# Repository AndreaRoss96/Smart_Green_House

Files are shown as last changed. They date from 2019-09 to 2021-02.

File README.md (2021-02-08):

# Smart_Green_House
integrated embedded system that represents a simplified version of a smart greenhouse.

The task of the smart greenhouse is the automated irrigation (of a certain soil or plant) by implementing a strategy that takes into account the perceived humidity, with the possibility to control and intervene manually via mobile app.

The system is composed by 5 subsystems:
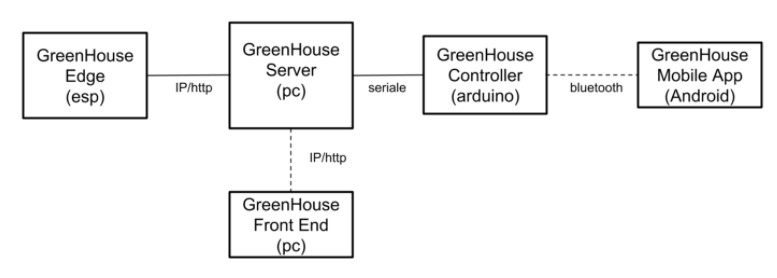
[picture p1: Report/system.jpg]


 * GreenHouse Server (PC)
    - contains the logic that defines and implements the irrigation strategy
 * GreenHouse Controller (Arduino)
   - allows you to control the opening and closing of the sprinklers (water pumps), thus the amount of water delivered per minute
 * GreenHouse Edge (ESP)
   - allows you to sense the humidity of the soil
 * GreenHouse Mobile App (Android) 
   - allows manual control of the greenhouse 
 * GreenHouse Front End (PC)
   - Front end for data visualisation/observation/analysis

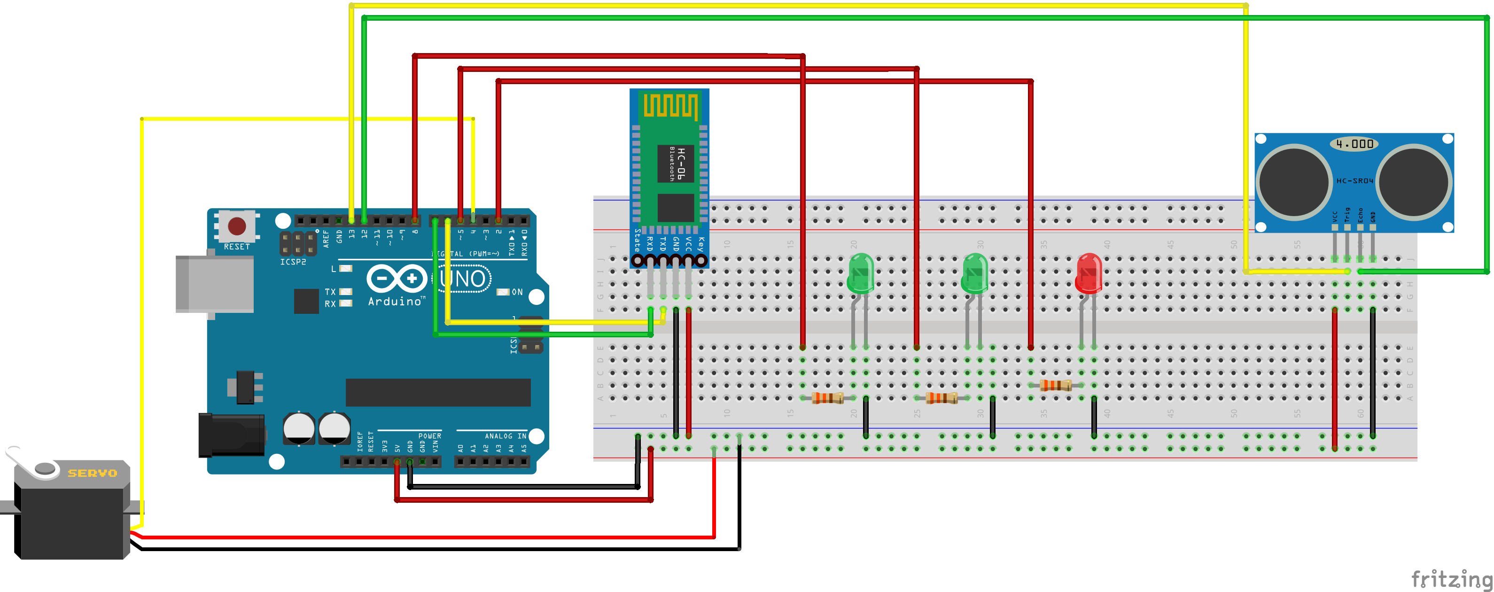
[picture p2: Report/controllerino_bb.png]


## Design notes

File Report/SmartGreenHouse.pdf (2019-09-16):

## Ingegneria e scienze informatiche (Cesena)

A.A 2018/19

## Valentini Luca Rossolini Andrea Orazi Filippo

obiettivi | 2
Analisi | 3
GreenHouse Controller | 3
Mobile App | 3
Progettazione | 4
Mobile App | 4
Microcontrollore | 4
Protocollo di comunicazione | 5
Edge ESP8266 | 6
Java Server (PC) | 6

# SmartGreenHouse

# obiettivi

Realizzare un sistema embedded che rappresenti una versione semplificata di una serra smart.
Il compito della serra smart è l’irrigazione automatizzata (di un certo terreno o pianta) implementando una strategia che tenga conto dell’umidità percepita, con la possibilità di controllare e intervenire manualmente mediante mobile app.

# Analisi

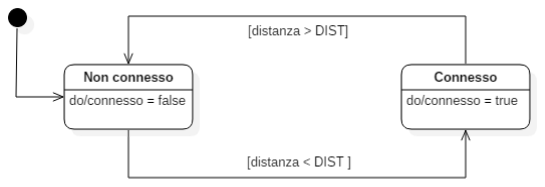
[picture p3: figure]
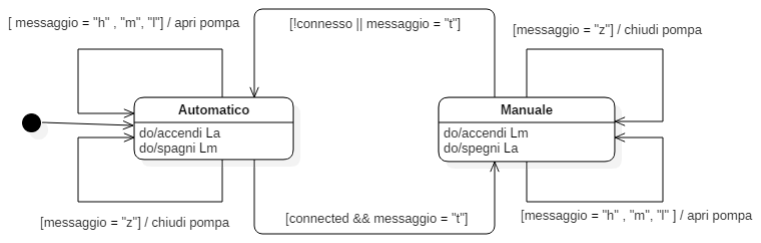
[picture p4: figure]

## GreenHouse Controller

Permette di controllare l’apertura e chiusura degli irrigatori (pompe acqua), quindi della quantità di acqua erogata al minuto. Riceve messaggi da bluetooth (se il dispositivo è nelle vicinanze) e da serial e li interpreta in modo da gestire la pompa.

## GreenHouse Edge

Percepisce l’umidità del terreno e la invia al server tramite Wifi.

## GreenHouse Server

Event driven loop che gestisce la comunicazione tra edge controller e front end, definisce e attua la strategia di irrigazione.

## GreenHouse Front End

Permette di osservare e analizzare dati

## Mobile App

L’app Android permetterà il controllo manuale della serra in maniera remota tramite bluetooth.
Considerando di essere nelle vicinanze della serra a una distanza dal Controller inferiore o uguale a 30 cm, deve essere possibile connettersi al sistema e passare a una modalità MANUALE in cui mediante l’app si possa:
- manualmente aprire/chiudere/regolare l’erogazione dell’acqua.
- visualizzare il valore corrente dell’umidità percepita.

# Progettazione

L’approccio da noi utilizzato nello sviluppo di questo software concorrente è la decomposizione del comportamento complessivo in più task:
– Ogni task rappresenta una fase ben definita, con un relativo compito da svolgere.
– Il comportamento di ogni task viene rappresentato da un elemento della macchina a stati, come rappresentato in figura.

## Mobile App

L’app è sviluppata in java in una singola activity chiamata MainActivity.
Questa schermata permetterà di svolgere tutte le funzioni richieste in fase di analisi, come:
- connessione ad arduino via bluetooth
- visualizzazione dello stato della connessione
- modalità automatica o manuale
- chiusura o apertura della pompa
- percentuale di umidità.

Per un corretto funzionamento dell’app è importante che prima di utilizzarla si effettui la connessione bluetooth con arduino, in modo tale da poter avere un canale di comunicazione tra lo smartphone e il micro-controllore.
A connessione avvenuta l’utente potrà cliccare i radio button per l’apertura e chiusura della pompa.
La comunicazione con arduino è bidirezionale, ovvero entrambi invieranno e riceveranno dei dati.

Ad ogni click dei pulsanti l’app invierà ad arduino una stringa secondo il protocollo di comunicazione da noi creato. Un’altra importante funzionalità è quella di ricevere informazioni relative alla percentuale di umidità.

## Microcontrollore

Il microcontrollore arduino viene impiegato per mantenere la logica di funzionamento degli attuatori e sensori della serra ad esclusione del sensore di umidità. L'arduino ha il compito di verificare l'eventuale connessione di un utente attraverso il sensore di distanza, in caso di utente sufficientemente vicino questo viene considerato connesso tramite bluetooth. Lo stato di connessione e di non connessione rappresentano i primi due stati della macchina e le loro meccaniche sono incapsulate nella classe TaskSearch.

Compito del microcontrollore è anche quello di gestire e interpretare i messaggi che gli arrivano sia dal server tramite seriale sia dalla Mobile App tramite bluetooth. Per fare ciò è presente la classe TaskComunicate che, con riferimento allo stato della macchina presente nella classe globale, gestisce e valuta i messaggi inerenti allo stato del controllore azionando in maniera coerente la pompa di irrigazione con lo stato di controllo del sistema (Manuale o Automatico)

### Protocollo di comunicazione

| invio di messaggi verso bluetooth
xx-a | xx percentuale di umidità nell'aria - modalità automatica
xx-m | xx percentuale di umidità nell'aria - modalità manuale
| invio di messaggi verso server
o | pompa aperta (open)
c | pompa chiusa (close)
0 | modalità automatica
1 | modalità manuale

| ricezione di messaggi
l | portata bassa (low)
m | portata media (medium)
h | portata alta (high)
z | portata nulla (zero)
Hxx | umidità percentuale = xx (humidity)

## Edge ESP8266

Il modulo ESP ha il solo scopo di misurare gli indici di umidità del terreno, tramite un modulo DHT11 (Nel codice implementato, tutto ciò che concerne questo modulo è commentato, poiché al suo posto, per semplice comodità, viene utilizzato un potenziometro, in questo modo siamo in grado di regolare manualmente l’umidità per svolgere le dovute analisi), ed inviarle al server.

Infatti l’edge misura l’umidità ogni 10 secondi, incapsulando questa informazione in un file Json che, all’interno di un pacchetto HTTP, viene inviata al server.

L’invio del pacchetto avviene tramite il software “Ngrok”, questo programma fornisce un indirizzo verso il quale, il microcontrollore, può facilmente comunicare; il server e l’ESP dovranno però essere connessi alla stessa rete wifi. Ngrok si occuperà di fare ‘tunneling’, ascoltando i messaggi in arrivo all'indirizzo da lui messo a disposizione, verso una determinata porta del localhost.

## Java Server (PC)

Il server contiene la logica che gestisce Arduino quando è nello stato “Automatico”; tramite la comunicazione seriale infatti è possibile inviare i messaggi (rispettando il protocollo succitato) per controllare il livello dell’irrigazione, aprire/chiudere la pompa e per inviare le informazioni sul livello di umidità (che poi il microcontrollore si invierà all’eventuale utente connesso tramite la mobile App).

Il server salva inoltre le informazioni relative all’umidità, all’apertura e alla chiusura della pompa, in un file testuale che può essere visualizzato sul browser tramite una semplice pagina php da noi creata.

La comunicazione con l'edge ESP avviene tramite protocollo IP/HTTP. Infatti il server rimane in ascolto sulla porta 8085, dove il programma Ngrok permette di fare tunneling. La classe DataService, che utilizza la libreria “Vertx”, è quella che riceve ed analizza i pacchetti inviatogli da ESP.

Il server implementa un pattern observable, dove le classi “osservabili” generano un evento che viene inserito all’interno di una lista dove, per ogni elemento, la classe “Observer” (BasicEventLoopController) li processa.

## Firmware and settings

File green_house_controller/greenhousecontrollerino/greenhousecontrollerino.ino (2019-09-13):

#include "MsgServiceBT.h"
#include "Task.h"
#include "TaskComunicate.h"
#include "TaskSearch.h"
#include "LevelIndicator.h"
#include "Led.h"
#include "Light.h"
#include "FadingLed.h"
#include "Sensor.h"
#include "Scheduler.h"
#include "ServoTimer2.h"
#include "Sonar.h"


#define BAUD 9600
#define PINECHO 12
#define PINTRIG 13

#define PINRX 7
#define PINTX 6

#define PINPORT 5
#define PINAUTO 8
#define PINMANU 2
#define PINSERVO 4

Scheduler scheduler;

/*
Parte principale del programma, inizializza i vari componenti e li fa interagire
*/

void setup(){
  Serial.begin(BAUD);
  Serial.flush();

  pinMode(PINRX,INPUT);
  pinMode(PINTX,OUTPUT);
  pinMode(PINPORT,OUTPUT);
  pinMode(PINAUTO,OUTPUT);
  pinMode(PINMANU,OUTPUT);
  pinMode(PINSERVO,OUTPUT);

  ServoTimer2 *servo = new ServoTimer2();
  Sensor *prox = new Sonar(PINECHO, PINTRIG);
  Light *la = new Led(PINAUTO);
  Light *lm = new Led(PINMANU);
  LevelIndicator *lp = new FadingLed(PINPORT);

  MsgServiceBT *msgServiceBT = new MsgServiceBT(PINRX, PINTX);
  msgServiceBT->init();
  MsgService.init();
  servo->attach(PINSERVO);
  servo->write(MIN_PULSE_WIDTH);
  lp->setLevel(MIN_LVL);

  Task *search = new TaskSearch(prox, la, lm);
  Task *comunicate = new TaskComunicate(msgServiceBT, la, lm, servo, lp);

  comunicate->init(500);
  search->init(1000);
  scheduler.init(500);
  scheduler.addTask(comunicate);
  scheduler.addTask(search);
}

void loop (){
  scheduler.schedule();
}

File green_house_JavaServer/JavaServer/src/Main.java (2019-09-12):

import java.io.IOException;

import controller.DataService;
import controller.EventLoopControllerImpl;
import controller.MsgService;
import controller.ObservableHumidityAgent;
import controller.PumpImpl;
import io.vertx.core.Vertx;

public class Main {

	public static void main(String[] args) throws IOException {
		final EventLoopControllerImpl eventLoopController;
		final ObservableHumidityAgent hAgent = new ObservableHumidityAgent();
		final PumpImpl pump = new PumpImpl();
		final MsgService msgService;
		final Vertx vertx = Vertx.vertx();
		final String port = "COM7"; /* replace with the name of the serial port */

		msgService = new MsgService(port, 9600);

		DataService service = new DataService(8085, hAgent);

		eventLoopController = new EventLoopControllerImpl(msgService, pump, hAgent);

		msgService.init();
		eventLoopController.start();
		vertx.deployVerticle(service);

		while (true) {
		}
	}
}

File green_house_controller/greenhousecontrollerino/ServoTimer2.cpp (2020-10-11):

extern "C" {
  // AVR LibC Includes
  #include <inttypes.h>
  #include <avr/interrupt.h>
  // #include "WConstants.h"
}
#include <Arduino.h>
#include "ServoTimer2.h"
static void initISR();   
static void writeChan(uint8_t chan, int pulsewidth);

#define FRAME_SYNC_INDEX   0		 // frame sync delay is the first entry in the channel array
#define FRAME_SYNC_PERIOD  20000	   // total frame duration in microseconds 
#define FRAME_SYNC_DELAY   ((FRAME_SYNC_PERIOD - ( NBR_CHANNELS * DEFAULT_PULSE_WIDTH))/ 128) // number of iterations of the ISR to get the desired frame rate
#define DELAY_ADJUST	 8		 // number of microseconds of calculation overhead to be subtracted from pulse timings   

static servo_t servos[NBR_CHANNELS+1];    // static array holding servo data for all channels

static volatile uint8_t Channel;   // counter holding the channel being pulsed
static volatile uint8_t ISRCount;  // iteration counter used in the interrupt routines;
uint8_t ChannelCount = 0;	    // counter holding the number of attached channels
static boolean isStarted = false;  // flag to indicate if the ISR has been initialised

ISR (TIMER2_OVF_vect)
{ 
  ++ISRCount; // increment the overlflow counter
  if (ISRCount ==  servos[Channel].counter ) // are we on the final iteration for this channel
  {
	TCNT2 =  servos[Channel].remainder;   // yes, set count for overflow after remainder ticks
  }  
  else if(ISRCount >  servos[Channel].counter)  
  {
	// we have finished timing the channel so pulse it low and move on
	if(servos[Channel].Pin.isActive == true)	     // check if activated
	    digitalWrite(servos[Channel].Pin.nbr,LOW); // pulse this channel low if active   

	  Channel++;    // increment to the next channel
	ISRCount = 0; // reset the isr iteration counter 
	TCNT2 = 0;    // reset the clock counter register
	if( (Channel != FRAME_SYNC_INDEX) && (Channel <= NBR_CHANNELS) ){	     // check if we need to pulse this channel    
	    if(servos[Channel].Pin.isActive == true)	   // check if activated
		 digitalWrite( servos[Channel].Pin.nbr,HIGH); // its an active channel so pulse it high   
	}
	else if(Channel > NBR_CHANNELS){ 
	   Channel = 0; // all done so start over		   
	} 
   }  
}

ServoTimer2::ServoTimer2()
{
   if( ChannelCount < NBR_CHANNELS)  
	this->chanIndex = ++ChannelCount;  // assign a channel number to this instance
   else
	this->chanIndex = 0;  // todo	// too many channels, assigning 0 inhibits this instance from functioning 
}

uint8_t ServoTimer2::attach(int pin)
{
	if( isStarted == false)
	 initISR();    
	if(this->chanIndex > 0)  
	{
	 //debug("attaching chan = ", chanIndex);
	 pinMode( pin, OUTPUT) ;  // set servo pin to output
	 servos[this->chanIndex].Pin.nbr = pin;  
	 servos[this->chanIndex].Pin.isActive = true;  
	} 
	return this->chanIndex ;
}

void ServoTimer2::detach()  
{
    servos[this->chanIndex].Pin.isActive = false;  
}

void ServoTimer2::write(int pulsewidth)
{	
   writeChan(this->chanIndex, pulsewidth); // call the static function to store the data for this servo	    
}

int ServoTimer2::read()
{
  unsigned int pulsewidth;
   if( this->chanIndex > 0)
	pulsewidth =  servos[this->chanIndex].counter * 128 + ((255 - servos[this->chanIndex].remainder) / 2) + DELAY_ADJUST ;
   else 
	 pulsewidth  = 0;
   return pulsewidth;   
}
 
boolean ServoTimer2::attached()
{
    return servos[this->chanIndex].Pin.isActive ;
}

static void writeChan(uint8_t chan, int pulsewidth)
{
   // calculate and store the values for the given channel
   if( (chan > 0) && (chan <= NBR_CHANNELS) )   // ensure channel is valid
   { 
	if( pulsewidth < MIN_PULSE_WIDTH )		    // ensure pulse width is valid
	    pulsewidth = MIN_PULSE_WIDTH;
	else if( pulsewidth > MAX_PULSE_WIDTH )
	    pulsewidth = MAX_PULSE_WIDTH;	 
	
	  pulsewidth -=DELAY_ADJUST;			 // subtract the time it takes to process the start and end pulses (mostly from digitalWrite) 
	servos[chan].counter = pulsewidth / 128;	
	servos[chan].remainder = 255 - (2 * (pulsewidth - ( servos[chan].counter * 128)));  // the number of 0.5us ticks for timer overflow	   
   }
}

static void initISR()
{   
	for(uint8_t i=1; i <= NBR_CHANNELS; i++) {  // channels start from 1    
	   writeChan(i, DEFAULT_PULSE_WIDTH);  // store default values	    
	}
	servos[FRAME_SYNC_INDEX].counter = FRAME_SYNC_DELAY;   // store the frame sync period	 

	Channel = 0;  // clear the channel index  
	ISRCount = 0;  // clear the value of the ISR counter;
	
	/* setup for timer 2 */
	TIMSK2 = 0;  // disable interrupts 
	TCCR2A = 0;  // normal counting mode 
	TCCR2B = _BV(CS21); // set prescaler of 8 
	TCNT2 = 0;     // clear the timer2 count 
	TIFR2 = _BV(TOV2);  // clear pending interrupts; 
	TIMSK2 =  _BV(TOIE2) ; // enable the overflow interrupt	  
	  
	isStarted = true;  // flag to indicate this initialisation code has been executed
} 

 

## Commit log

2019-04-20 cambiato il sorgente della parte arduino ora funziona
2019-05-20 non funzione il sndMsgBT
2019-09-11 ho sistematoa il codice osceno della budo, manca da sistemare quello di arduino per renderlo compatibile, lo faccio domani mattina
2019-09-11 aggiunto i messaggi lato arduino e sistemate le condizioni lato server secondo il protocollo descritto in taskcomunicate.cpp
2019-09-11 fritzing schemes done
    [controllerino.fzz, esp.fzz]
2019-09-12 Timer on server to check overtimepump
2019-09-13 usless print removed
2019-09-15 corretto schema fritzing
    [controllerino.fzz]
2019-09-15 ho cancellato i file inutili di android
2020-10-11 Code cleaned and schedule improvements
    [controllerino.fzz, esp.fzz]
2020-10-11 removed Relazione
    [controllerino.fzz, esp.fzz]
